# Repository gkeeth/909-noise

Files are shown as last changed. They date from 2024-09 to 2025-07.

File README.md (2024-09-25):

# 909-noise

Noise generator module for TR-909 drums. The form factor is a small
(20mm x 30mm) plug in module. Replicates the original LFSR design using a small
microcontroller.

Inputs: 12V, GND

Outputs: white noise signal equivalent to output from 909 shift register (12V
voltage level).

## License
Hardware design files are licensed under a [Creative Commons Attribution-ShareAlike 4.0
International License][cc-by-sa].

[][cc-by-sa]

Code is licensed under the MIT license.
[Greatest](https://github.com/silentbicycle/greatest) is licensed under ISC license.

[][mit-link]

[cc-by-sa]: http://creativecommons.org/licenses/by-sa/4.0/
[cc-by-sa-image]: https://licensebuttons.net/l/by-sa/4.0/88x31.png
[cc-by-sa-shield]: https://img.shields.io/badge/License-CC%20BY--SA%204.0-lightgrey.svg
[mit-link]: https://opensource.org/licenses/MIT
[mit-shield]: https://img.shields.io/badge/License-MIT-yellow.svg

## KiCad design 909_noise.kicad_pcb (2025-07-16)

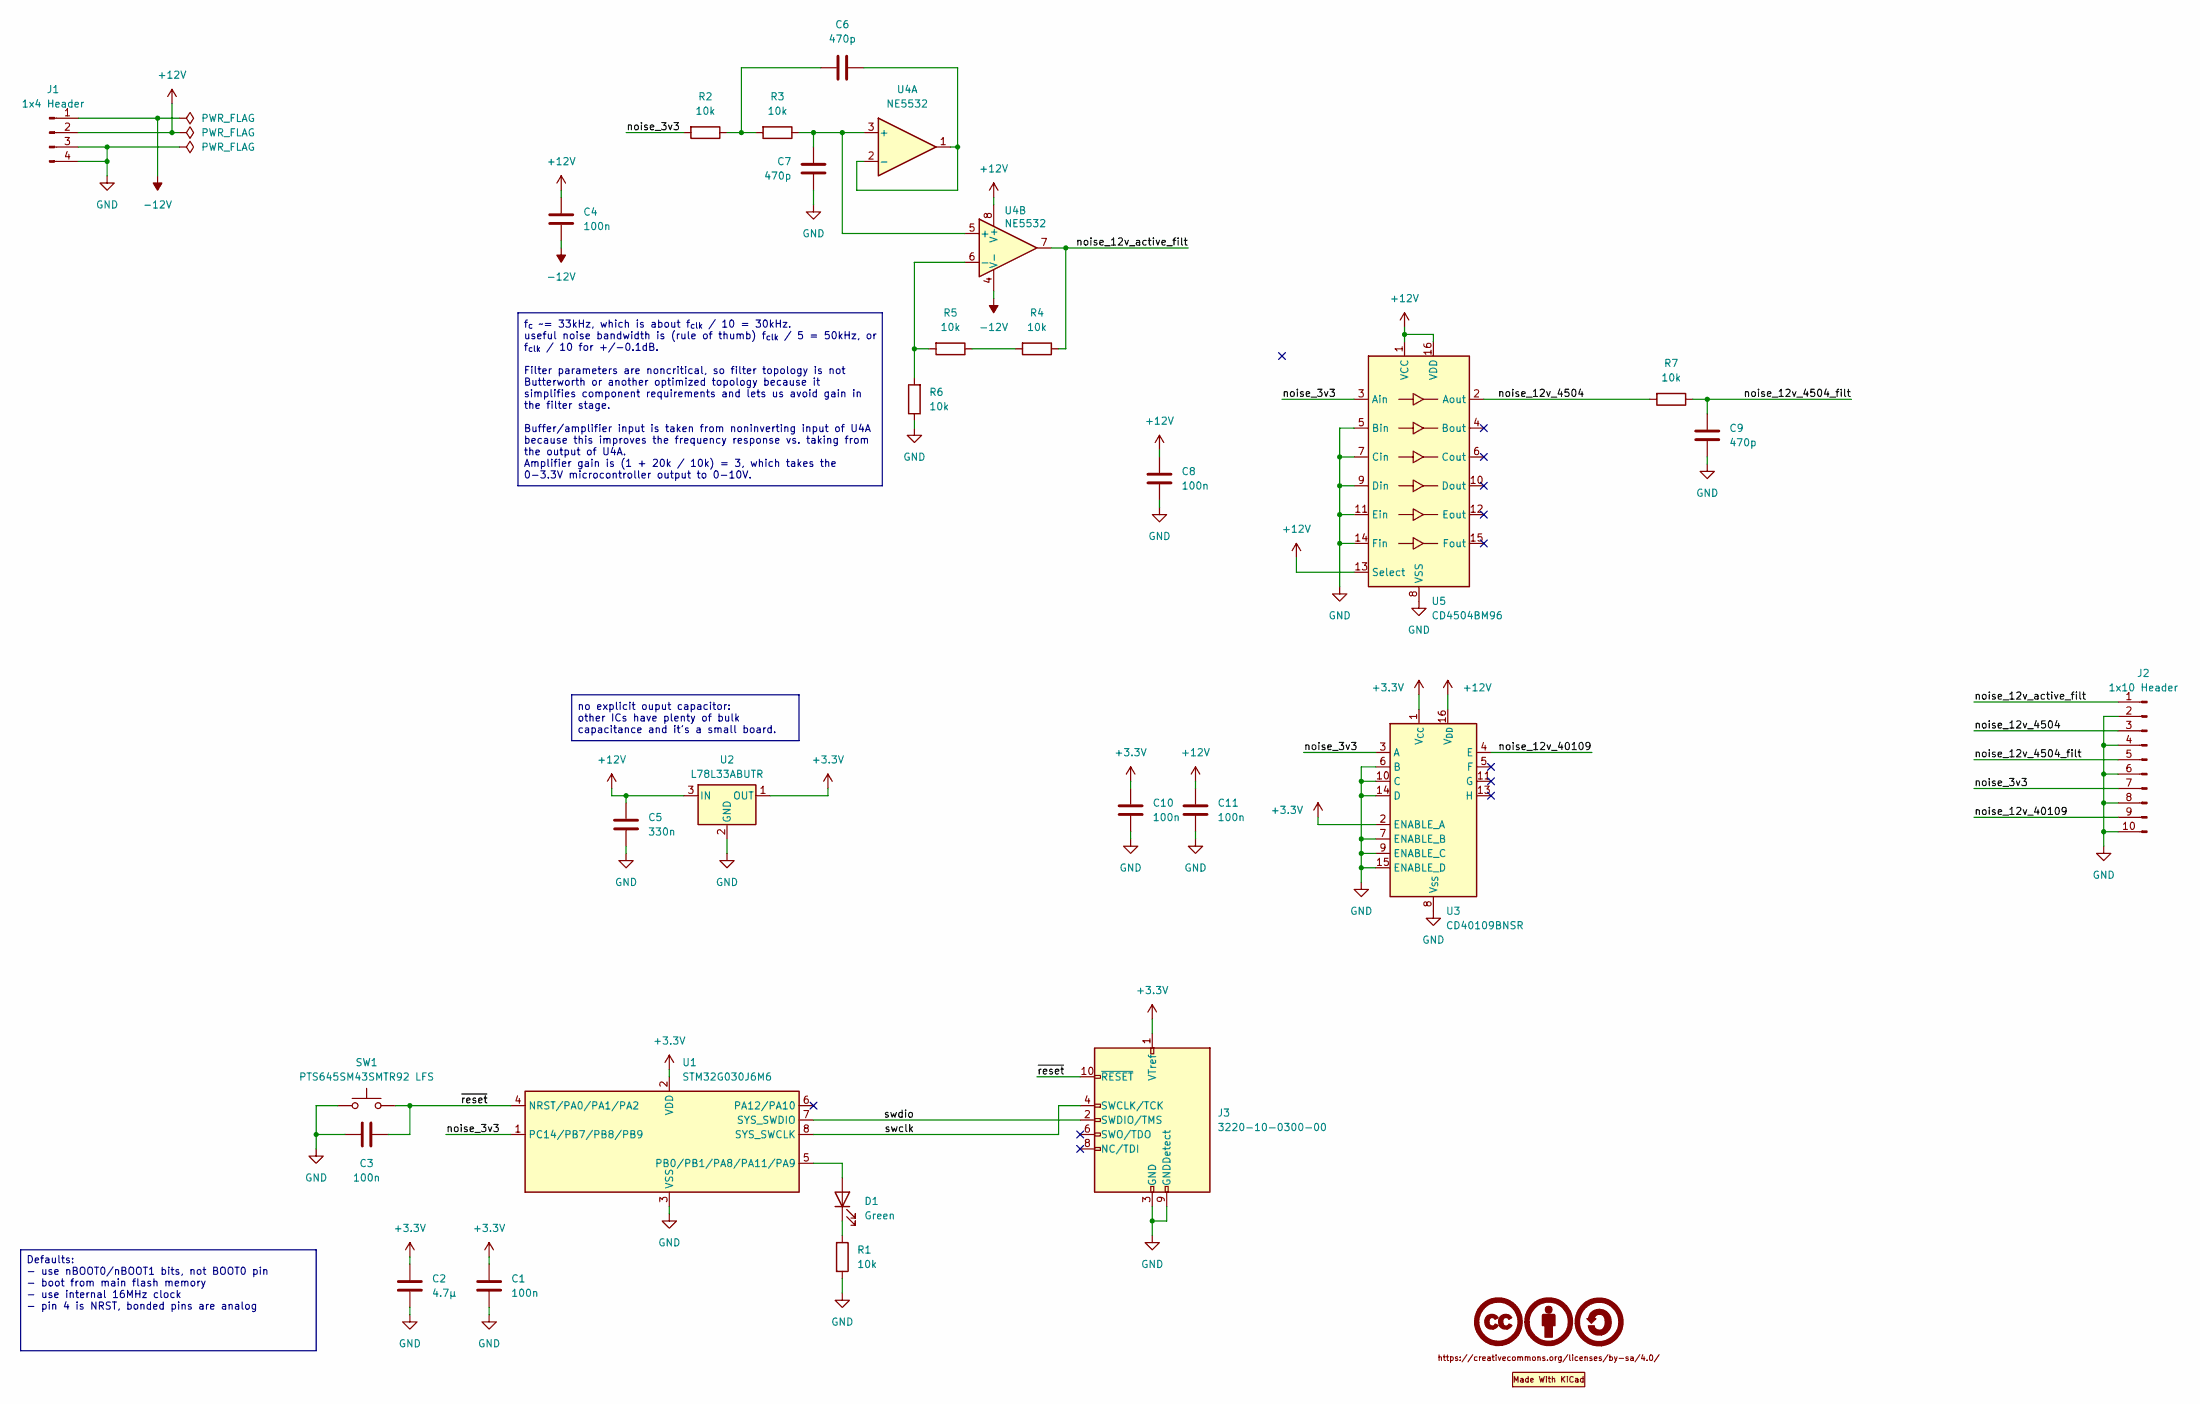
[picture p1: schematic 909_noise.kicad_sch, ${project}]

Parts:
C1, C3, C4, C8, C10, C11: 100n; C_0603_1608Metric; Tolerance 10%; Voltage Rating 50V
C2: 4.7μ; C_0805_2012Metric; Tolerance 10%; Voltage Rating 50V
C5: 330n; C_0603_1608Metric; Tolerance 10%; Voltage Rating 50V
C6, C7, C9: 470p; C_0603_1608Metric; Tolerance 5%; Voltage Rating 50V
D1: Green; LED_0603_1608Metric; Forward Voltage 2V; MPN LTST-C191KGKT
J1: 1x4 Header; PinHeader_1x04_P2.54mm_Vertical
J2: 1x10 Header; PinHeader_1x10_P2.54mm_Vertical
J3: 3220-10-0300-00; CNC_Tech_3220-10-0300-00_2x05_P1.27mm_Vertical; MPN 3220-10-0300-00
LOGO1: CC-BY-SA; CC-BY-SA_SilkScreenTop_Small
LOGO2: Made With KiCad; KiCad-Logo2_5mm_SilkScreen
R1, R2, R3, R4, R5, R6, R7: 10k; R_0603_1608Metric; Tolerance 1%; Power Rating 0.1W
SW1: PTS645SM43SMTR92 LFS; SW_SPST_PTS645; MPN PTS645SM43SMTR92 LFS
U1: STM32G030J6M6; SOIC-8_3.9x4.9mm_P1.27mm; MPN STM32G030J6M6
U2: L78L33ABUTR; SOT-89-3; Output Voltage 3.3V; MPN L78L33ABUTR
U3: CD40109BNSR; SOIC-16W_5.3x10.2mm_P1.27mm; MPN CD40109BNSR
U4: NE5532; SOIC-8_3.9x4.9mm_P1.27mm
U5: CD4504BM96; SOIC-16_3.9x9.9mm_P1.27mm; MPN CD4504BM96

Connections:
+3.3V: C1.2, C2.2, C10.2, J3.1 (VTref), U1.2 (VDD), U2.1 (OUT), U3.1 (V_{CC}), U3.2 (ENABLE_A)
+12V: C4.2, C5.2, C8.2, C11.2, J1.2, U2.3 (IN), U3.16 (V_{DD}), U4.8 (V+), U5.1 (VCC), U5.13 (Select), U5.16 (VDD)
-12V: C4.1, J1.1, U4.4 (V-)
/noise_3v3: J2.7, R2.2, U1.1 (PC14/PB7/PB8/PB9), U3.3 (A), U5.3 (Ain)
/noise_12v_4504: J2.3, R7.2, U5.2 (Aout)
/noise_12v_4504_filt: C9.1, J2.5, R7.1
/noise_12v_40109: J2.9, U3.4 (E)
/noise_12v_active_filt: J2.1, R4.1, U4.7
/swclk: J3.4 (SWCLK/TCK), U1.8 (SYS_SWCLK)
/swdio: J3.2 (SWDIO/TMS), U1.7 (SYS_SWDIO)
/~reset: C3.2, J3.10 (~RESET), SW1.2, U1.4 (NRST/PA0/PA1/PA2)
GND: C1.1, C2.1, C3.1, C5.1, C7.2, C8.1, C9.2, C10.1, C11.1, J1.3, J1.4, J2.2, J2.4, J2.6, J2.8, J2.10, J3.3 (GND), J3.5 (GND), J3.9 (GNDDetect), R1.2, R6.1, SW1.1, U1.3 (VSS), U2.2 (GND), U3.6 (B), U3.7 (ENABLE_B), U3.8 (V_{SS}), U3.9 (ENABLE_C), U3.10 (C), U3.14 (D), U3.15 (ENABLE_D), U5.5 (Bin), U5.7 (Cin), U5.8 (VSS), U5.9 (Din), U5.11 (Ein), U5.14 (Fin)
unnamed: C6.1, R2.1, R3.2
unnamed: D1.2 (A), U1.5 (PB0/PB1/PA8/PA11/PA9)
unnamed: D1.1 (K), R1.1
unnamed: R4.2, R5.1
unnamed: C7.1, R3.1, U4.3 (+), U4.5 (+)
unnamed: C6.2, U4.1, U4.2 (-)
unnamed: R5.2, R6.2, U4.6 (-)

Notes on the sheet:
f_{c} ~= 33kHz, which is about f_{clk} / 10 = 30kHz. useful noise bandwidth is (rule of thumb) f_{clk} / 5 = 50kHz, or f_{clk} / 10 for +/-0.1dB. Filter parameters are noncritical, so filter topology is not Butterworth or another optimized topology because it simplifies component requirements and l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
no explicit ouput capacitor: other ICs have plenty of bulk capacitance and it's a small board.
Defaults: - use nBOOT0/nBOOT1 bits, not BOOT0 pin - boot from main flash memory - use internal 16MHz clock - pin 4 is NRST, bonded pins are analog

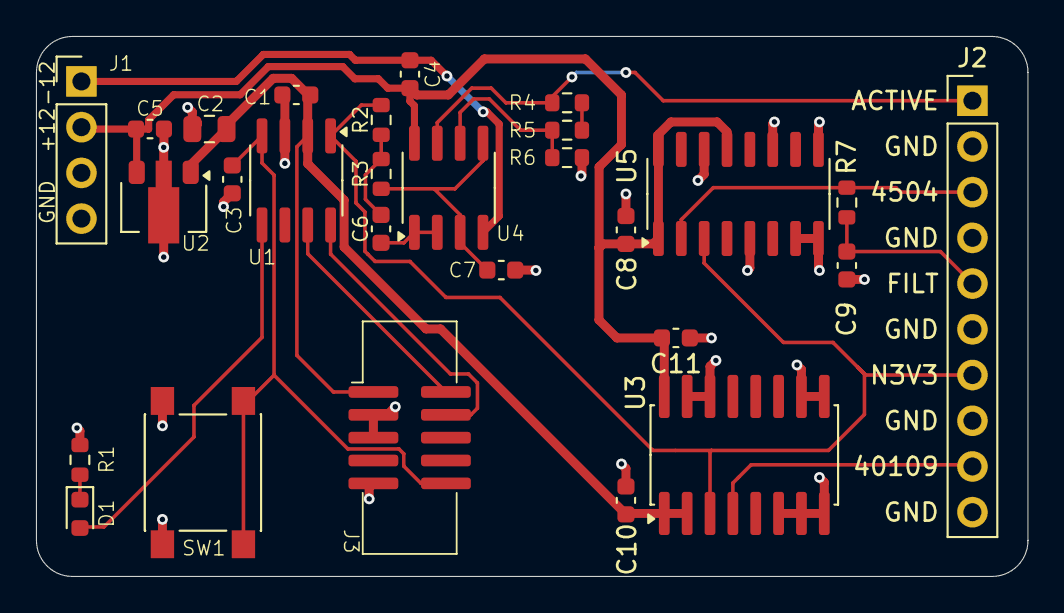
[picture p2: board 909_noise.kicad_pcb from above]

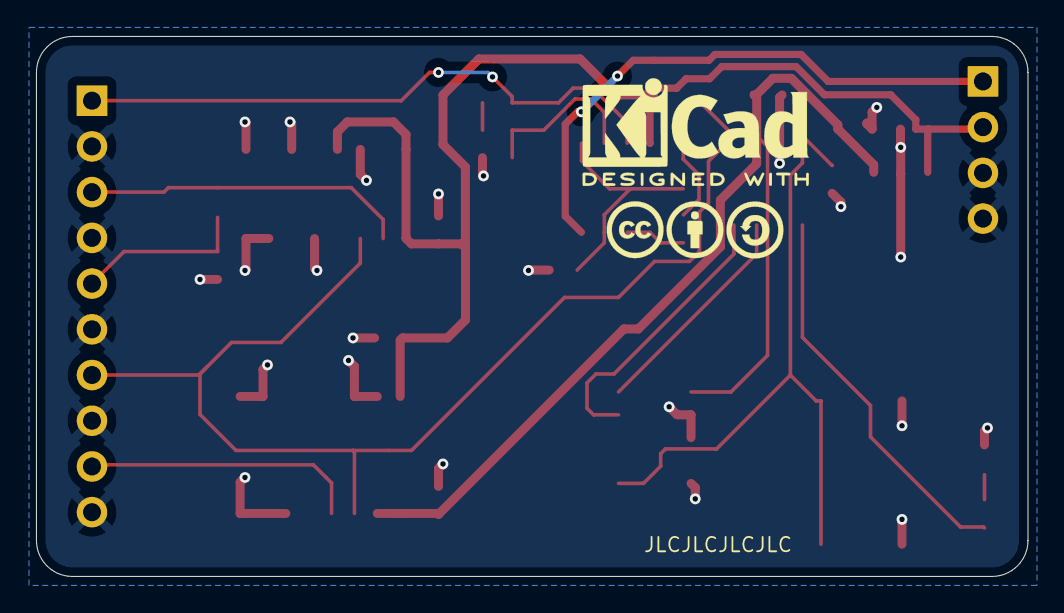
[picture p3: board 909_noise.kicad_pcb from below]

Board: 2 copper layers, 55.1 x 30.0 mm, 30 parts (2 on the bottom side), 19 nets.

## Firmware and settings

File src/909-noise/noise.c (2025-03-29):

// example based on libopencm3 miniblink/systick_blink/button examples

#include <libopencm3/stm32/rcc.h>
#include <libopencm3/stm32/gpio.h>
#include <libopencm3/stm32/timer.h>
#include <libopencm3/cm3/nvic.h>
#include <libopencm3/cm3/systick.h>

#include "lfsr.h"

// LED is PB0/PB1/PA8/PA11/PA9, and we pick PB0
#define PORT_LED GPIOB
#define PIN_LED GPIO0 // noise pin is PC14/PB7/PB8/PB9, and we pick PB7
#define PORT_NOISE GPIOB
#define PIN_NOISE GPIO7
#define TIM_NOISE TIM3

volatile uint32_t counter = 0;

void tim34_isr(void) {
    if (timer_interrupt_source(TIM_NOISE, TIM_SR_UIF)) {
        static uint32_t lfsr = 0xFFFFFFFF;
        uint32_t output;
        lfsr_step(&lfsr, &output);
        if (output) {
            gpio_set(PORT_NOISE, PIN_NOISE);
        } else {
            gpio_clear(PORT_NOISE, PIN_NOISE);
        }

        timer_clear_flag(TIM_NOISE, TIM_SR_UIF);
    }
}

void sys_tick_handler(void) {
    ++counter;
}

uint32_t millis(void);
uint32_t millis(void) {
    return counter;
}

static void setup(void) {
    rcc_clock_setup(&rcc_clock_config[RCC_CLOCK_CONFIG_HSI_PLL_64MHZ]);

    STK_CVR = 0; // clear systick current value to start immediately

    // every 1 ms (1000 Hz)
    systick_set_frequency(1000, rcc_ahb_frequency);
    systick_counter_enable();
    systick_interrupt_enable();

    // setup LED pins
    rcc_periph_clock_enable(RCC_GPIOB);
    // set LED pins to output push-pull
    gpio_mode_setup(PORT_LED, GPIO_MODE_OUTPUT, GPIO_PUPD_NONE, PIN_LED);

    // setup noise pin
    gpio_mode_setup(PORT_NOISE, GPIO_MODE_OUTPUT, GPIO_PUPD_NONE, PIN_NOISE);

    // setup timer
    rcc_periph_clock_enable(RCC_TIM3);
    // rcc_ahb_frequency = 64MHz
    // desired noise fclk = ~300kHz
    // period of 213 - 1 gives 300.5kHz
    timer_set_prescaler(TIM_NOISE, 0);
    timer_set_period(TIM_NOISE, 212);
    timer_enable_irq(TIM_NOISE, TIM_DIER_UIE);
    nvic_enable_irq(NVIC_TIM34_IRQ);
    timer_enable_counter(TIM_NOISE);
}


int main(void) {
    setup();

    const uint32_t BLINK_DELAY = 500;
    uint32_t last_flash_millis = millis();

    while(1) {
        if ((millis() - last_flash_millis) > BLINK_DELAY) {
            gpio_toggle(PORT_LED, PIN_LED);
            last_flash_millis = millis();
        }
    }

    return 0;
}

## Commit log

2024-05-05 inital commit with schematic
    [909_noise.kicad_pcb, 909_noise.kicad_sch]
2024-05-05 initial placement, schematic tweaks
    [909_noise.kicad_pcb, 909_noise.kicad_sch]
2024-05-05 add output filter
    [909_noise.kicad_pcb, 909_noise.kicad_sch]
2024-05-05 quick silk adjust
    [909_noise.kicad_pcb]
2024-05-05 add netclasses and a gnd fill
    [909_noise.kicad_pcb]
2024-05-05 initial layout
    [909_noise.kicad_pcb]
2024-05-05 fillet board outline
    [909_noise.kicad_pcb]
2024-05-05 flip connectors to bottom
    [909_noise.kicad_pcb]
2024-05-05 adjust connector position and add connector dims
    [909_noise.kicad_pcb]
2024-05-05 add decals to back of board, rearrange silk slightly
    [909_noise.kicad_pcb, 909_noise.kicad_sch]
2024-05-05 change to cheaper debug connector
    [909_noise.kicad_pcb, 909_noise.kicad_sch]
2024-05-05 fix pads somehow not having mask/paste layers
    [909_noise.kicad_pcb]
2024-05-05 add github url and update back silkscreen
    [909_noise.kicad_pcb]
2024-05-05 cleanup footprint attributes between pcb and sch
    [909_noise.kicad_pcb, 909_noise.kicad_sch]
2024-05-09 tweak silk and footprint placement
    [909_noise.kicad_pcb]
2024-05-10 fix overlapping courtyards
    [909_noise.kicad_pcb]
2024-05-19 swap symbols for specified symbols from dblib
    [909_noise.kicad_pcb, 909_noise.kicad_sch]
2024-09-22 add libopencm3 and a working blink example
    [stm32g0.cfg]
2024-09-24 initial noise application (just square wave)
    [noise.c]
2024-09-25 add sim of clock oscillator from original 909
    [clock.kicad_pcb, clock.kicad_sch]
2024-11-27 routed with single-supply +12V on opamp
    [909_noise.kicad_pcb, 909_noise.kicad_sch]
2024-11-27 add -12V to opamp
    [909_noise.kicad_pcb, 909_noise.kicad_sch]
2024-11-27 remove screenshot from schematic
    [909_noise.kicad_sch]
2024-11-27 update issue date in schematic and board
    [909_noise.kicad_pcb, 909_noise.kicad_sch]
2024-12-05 fix netclass assignments
    [909_noise.kicad_sch]
2024-12-05 adjust routing for minimizing ground plane interruption
    [909_noise.kicad_pcb]
2025-03-16 fixup unit test framework
2025-03-29 save in kicad 9
    [909_noise.kicad_pcb, 909_noise.kicad_sch]
2025-07-16 r0.3 schematic/layout
    - change active filter values to filter at lower freq
    - add raw 3V3 output
    - add two types of level shifters to 12V
    - add passively filtered 12V output
    [909_noise.kicad_pcb, 909_noise.kicad_sch]
2025-07-16 add jlc order number locator
    [909_noise.kicad_pcb]

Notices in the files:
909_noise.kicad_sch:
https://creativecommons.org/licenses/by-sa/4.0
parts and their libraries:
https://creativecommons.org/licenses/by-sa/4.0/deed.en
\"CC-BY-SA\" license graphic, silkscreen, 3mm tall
